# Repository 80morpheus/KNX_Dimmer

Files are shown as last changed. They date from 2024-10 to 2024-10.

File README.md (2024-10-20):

# KNX Dimmer
up to 16 channels possible
depends on the configuration

W = Single
CW = Cold/Warm White
RGB = RGB
RGBW = RGB+White
RGBCW = RGB+Cold/Warm White

Possible outputs:
3X  RGBCW
or
4x  RGBW
or
5X  RGB
or
8X  CW
or
16X W

CH1  S CW RGB RGBW RGBCW 
CH2  S CW RGB RGBW RGBCW 
CH3  S CW RGB RGBW RGBCW 
CH4  S CW RGB RGBW  
CH5  S CW RGB  
CH6  S CW      
CH7  S CW      
CH8  S CW      
CH9  S        
CH10 S        
CH11 S        
CH12 S        
CH13 S        
CH14 S        
CH15 S        
CH16 S         

# dimm bedingung
wenn abs oder rel dimmen dann nur bis min wert
wenn ausschalten, dann aus und optional farbwerte auf standard zurück setzen

single ist easy -> zwischen min und max

cw -> ginge auch zwischen min und max
      cw werte ??? müßte zwei min um evtl aus zu vermeiden
      ets eingabe farbtemp für c + w
      ets regler für temperatur gibt prozentual an welche der beiden wo steht
      links = nur c wird gesteuert und w ist dann 0
      mitte = beide selber wert
      rechts = nur w wird gesteuert und c ist dann 0

rgb -> dimmt nur von 0 bis setpoint
      min wert macht keinen sinn da dann zu komplizierte berechnungen

rgbw -> siehe rgb
      wie wird w behandelt ??? einzelnes licht objekt

rgbcw -> wie wird c und w behandelt ??? einzelnes licht objekt
      ets eingabe farbtemp für c + w
      ets standard wert - wird nach aus wieder aktiv ja/nein
      rgb dimmt von 0 bis setpoint

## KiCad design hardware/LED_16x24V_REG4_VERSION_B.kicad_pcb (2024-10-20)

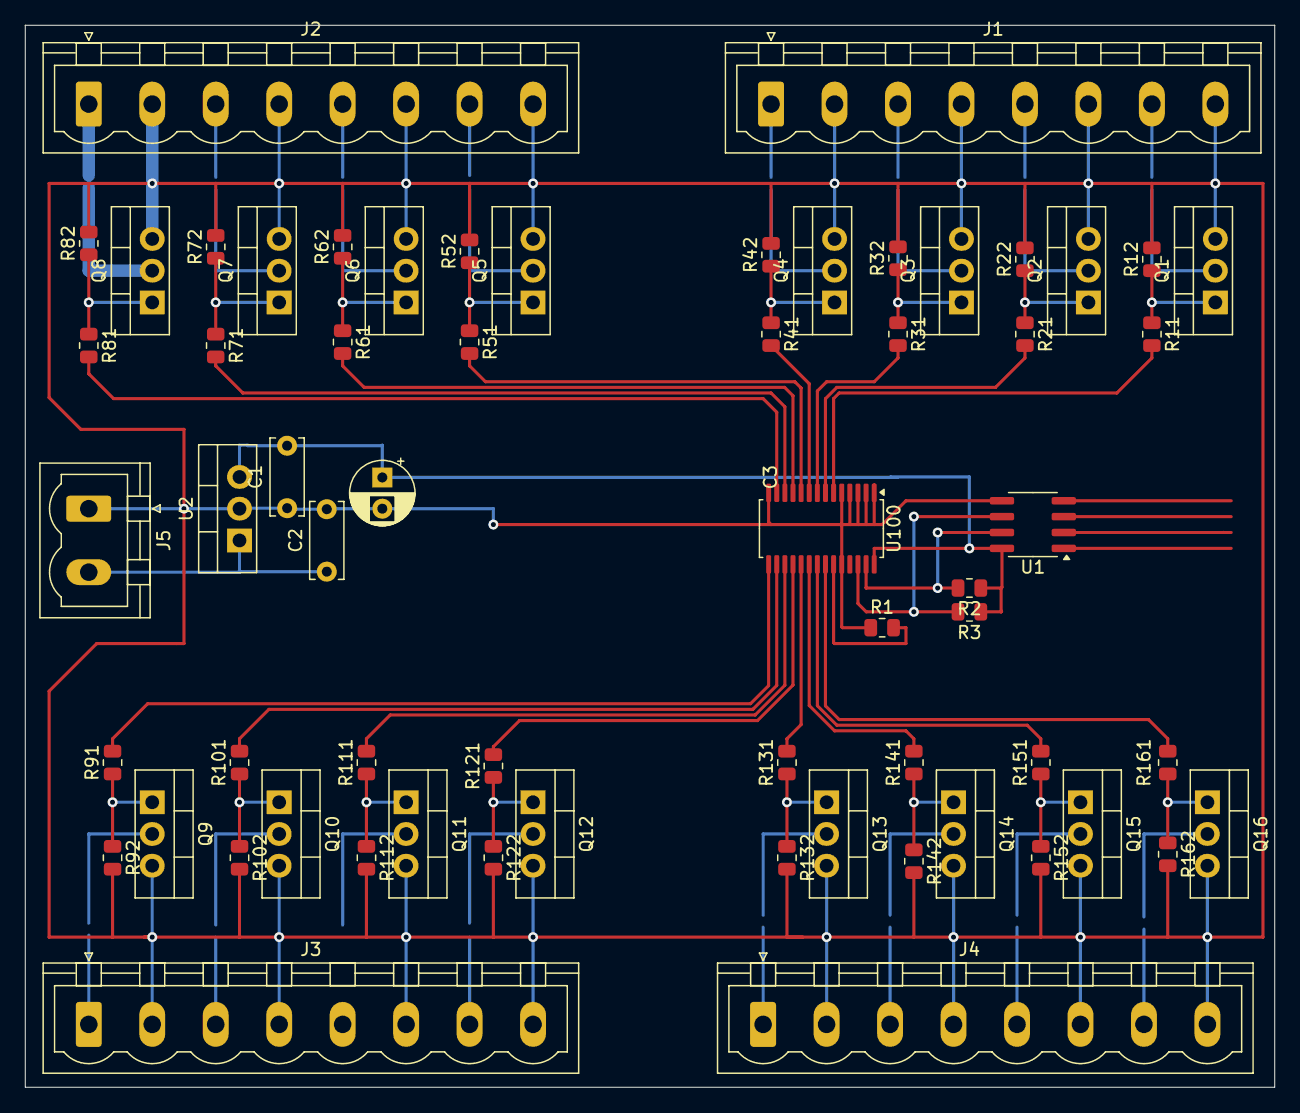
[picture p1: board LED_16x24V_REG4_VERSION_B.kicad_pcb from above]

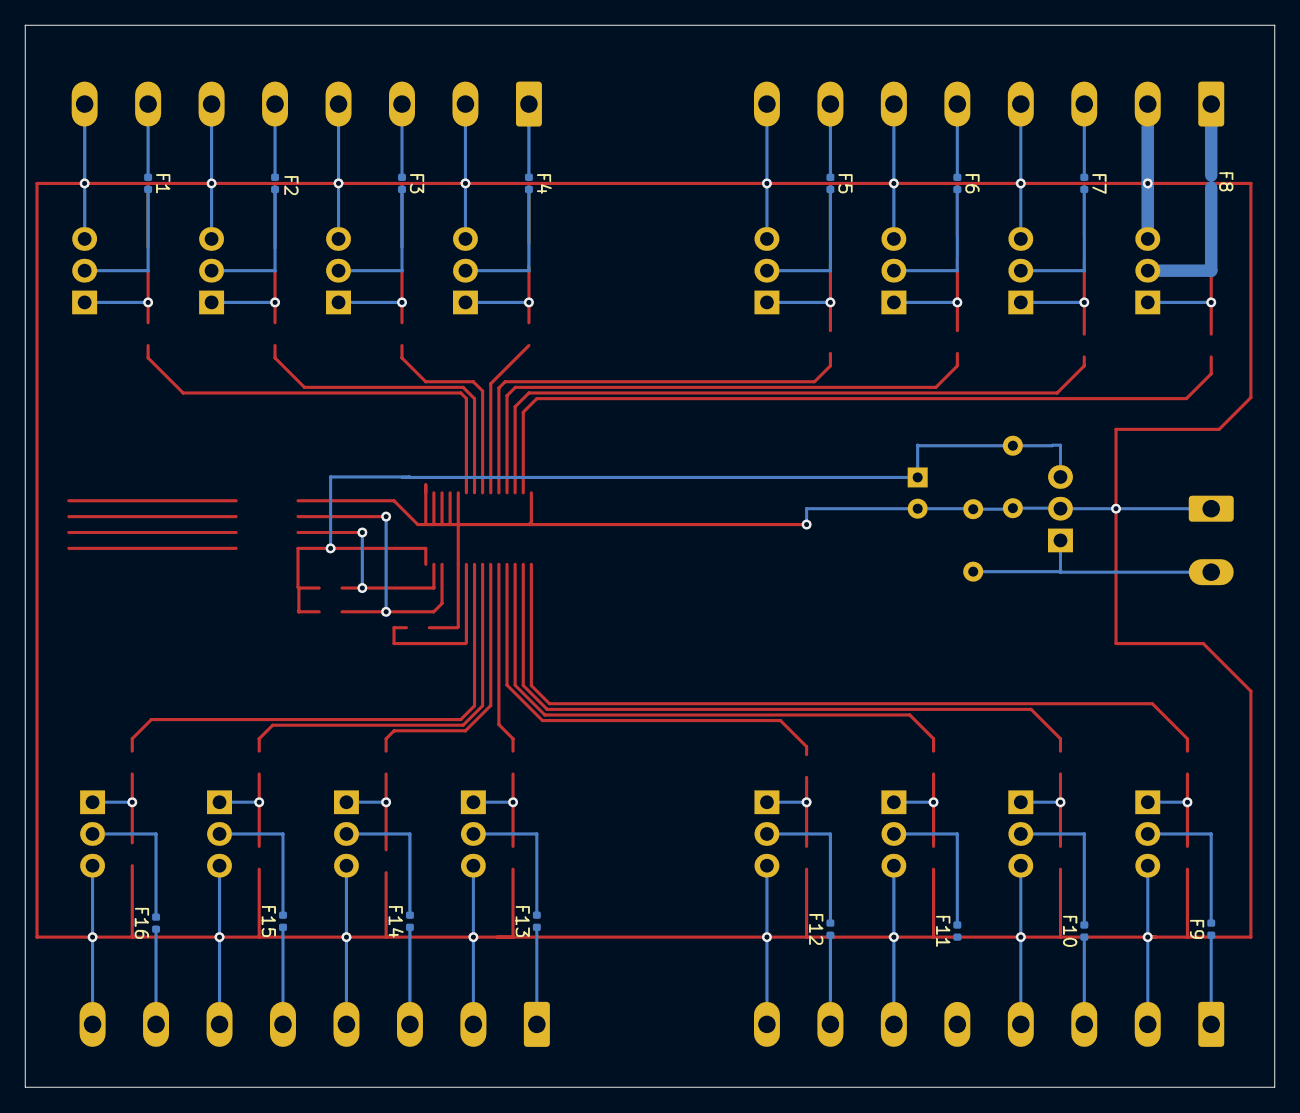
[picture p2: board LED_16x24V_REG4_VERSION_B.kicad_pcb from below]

Board: 2 copper layers, 100.0 x 85.0 mm, 78 parts (16 on the bottom side), 66 nets.

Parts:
C1: 0.1µF; C_Disc_D6.0mm_W2.5mm_P5.00mm
C2: 0.33µF; C_Disc_D6.0mm_W2.5mm_P5.00mm
C3: 100µF; CP_Radial_D5.0mm_P2.50mm
F1, F2, F3, F4, F5, F6, F7, F8, F9, F10, F11, F12, F13, F14, F15, F16: Fuse; Fuse_0402_1005Metric
J1, J2, J3, J4: Conn_01x08; PhoenixContact_MSTBVA_2,5_8-G-5,08_1x08_P5.08mm_Vertical
J5: Conn_01x02; PhoenixContact_MSTBVA_2,5_2-G-5,08_1x02_P5.08mm_Vertical
Q1, Q2, Q3, Q4, Q5, Q6, Q7, Q8, Q9, Q10, Q11, Q12, Q13, Q14, Q15, Q16: IRF3205; TO-220-3_Vertical
R1, R11, R12, R21, R22, R31, R32, R41, R42, R51, R52, R61, R62, R71, R72, R81, R82, R91, R92, R101, R102, R111, R112, R121, R122, R131, R132, R141, R142, R151, R152, R161, R162: R; R_0805_2012Metric
R2, R3: 10k; R_0805_2012Metric
U1: ADuM1250; SOIC-8_3.9x4.9mm_P1.27mm
U2: L7806; TO-220-3_Vertical
U100: PCA9685PW; TSSOP-28_4.4x9.7mm_P0.65mm

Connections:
GND_LED: C1.1, C2.2, C3.2, F7.1, F7.2, F8.1, F8.2, J1.2, J1.4, J1.6, J1.8, J2.1, J2.2, J2.3, J2.4, J2.6, J2.8, J3.2, J3.4, J3.6, J3.8, J4.2, J4.4, J4.6, J4.8, J5.1, Q1.3 (S), Q2.3 (S), Q3.3 (S), Q4.3 (S), Q5.3 (S), Q6.3 (S), Q7.2 (D), Q7.3 (S), Q8.2 (D), Q8.3 (S), Q9.3 (S), Q10.3 (S), Q11.3 (S), Q12.3 (S), Q13.3 (S), Q14.3 (S), Q15.3 (S), Q16.3 (S), R1.1, R12.2, R22.2, R32.2, R42.2, R52.2, R62.2, R72.2, R82.2, R92.2, R102.2, R112.2, R122.2, R132.2, R142.2, R152.2, R162.2, U1.5 (GND2), U2.2 (GND), U100.1 (A0), U100.2 (A1), U100.3 (A2), U100.4 (A3), U100.5 (A4), U100.14 (VSS), U100.24 (A5)
unnamed: F4.1, J1.1
unnamed: F3.1, J1.3
unnamed: F2.1, J1.5
unnamed: F1.1, J1.7
unnamed: F6.1, J2.5
unnamed: F5.1, J2.7
unnamed: F9.1, J3.1
unnamed: F10.1, J3.3
unnamed: F11.1, J3.5
unnamed: F12.1, J3.7
unnamed: F13.1, J4.1
unnamed: F14.1, J4.3
unnamed: F15.1, J4.5
unnamed: F16.1, J4.7
unnamed: C2.1, J5.2, U2.1 (IN)
unnamed: F1.2, Q1.2 (D)
unnamed: Q1.1 (G), R11.1, R12.1
unnamed: F2.2, Q2.2 (D)
unnamed: Q2.1 (G), R21.1, R22.1
unnamed: F3.2, Q3.2 (D)
unnamed: Q3.1 (G), R31.1, R32.1
unnamed: F4.2, Q4.2 (D)
unnamed: Q4.1 (G), R41.1, R42.1
unnamed: F5.2, Q5.2 (D)
unnamed: Q5.1 (G), R51.1, R52.1
unnamed: F6.2, Q6.2 (D)
unnamed: Q6.1 (G), R61.1, R62.1
unnamed: Q7.1 (G), R71.1, R72.1
unnamed: Q8.1 (G), R81.1, R82.1
unnamed: F9.2, Q9.2 (D)
unnamed: Q9.1 (G), R91.1, R92.1
unnamed: F10.2, Q10.2 (D)
unnamed: Q10.1 (G), R101.1, R102.1
unnamed: F11.2, Q11.2 (D)
unnamed: Q11.1 (G), R111.1, R112.1
unnamed: F12.2, Q12.2 (D)
unnamed: Q12.1 (G), R121.1, R122.1
unnamed: F13.2, Q13.2 (D)
unnamed: Q13.1 (G), R131.1, R132.1
unnamed: F14.2, Q14.2 (D)
unnamed: Q14.1 (G), R141.1, R142.1
unnamed: F15.2, Q15.2 (D)
unnamed: Q15.1 (G), R151.1, R152.1
unnamed: F16.2, Q16.2 (D)
unnamed: Q16.1 (G), R161.1, R162.1
unnamed: R3.2, U1.6 (SCL2), U100.26 (SCL)
unnamed: R2.2, U1.7 (SDA2), U100.27 (SDA)
unnamed: C1.2, C3.1, R2.1, R3.1, U1.8 (VDD2), U2.3 (OUT), U100.28 (VDD)
unnamed: R11.2, U100.6 (LED0)
unnamed: R21.2, U100.7 (LED1)
unnamed: R31.2, U100.8 (LED2)
unnamed: R41.2, U100.9 (LED3)
unnamed: R51.2, U100.10 (LED4)
unnamed: R61.2, U100.11 (LED5)
unnamed: R71.2, U100.12 (LED6)
unnamed: R81.2, U100.13 (LED7)
unnamed: R91.2, U100.15 (LED8)
unnamed: R101.2, U100.16 (LED9)
unnamed: R111.2, U100.17 (LED10)
unnamed: R121.2, U100.18 (LED11)
unnamed: R131.2, U100.19 (LED12)
unnamed: R141.2, U100.20 (LED13)
unnamed: R151.2, U100.21 (LED14)
unnamed: R161.2, U100.22 (LED15)
unnamed: R1.2, U100.23 (~OE)

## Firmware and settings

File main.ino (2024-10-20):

#include <Arduino.h>
#define MASK_VERSION 0x07B0
#define USE_RP2040_EEPROM_EMULATION
#include <knx.h>
//#include <Wire.h>
#include "dimmer.h"
int ch_num = 0;
Dimmer dimmer(2);







void setup() 
{
    knx.readMemory();
    if ( knx.configured() )
    {
      //Wire.begin();
      dimmer.init();
      for ( int i=1; i<17; i++)
      {
              if ( knx.paramInt(i*10) > 0 )   {ch_num++ ;  }
      }
      dimmer.knxParam(ch_num);

      dimmer.setGroupObject();
      dimmer.setupCallback();
    }
    else
    {
          knx.progMode(true);
    }
  dimmer.setStart();
}



void loop()
{
    knx.loop();
    if ( knx.configured() )
    {
          dimmer.loop();
    }

}

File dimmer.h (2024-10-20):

#include <Arduino.h>
#include <knx.h>

#ifndef Dimmer_h
#define Dimmer_h

#define go_ch01_switch knx.getGroupObject(10)
#define go_ch01_reldim knx.getGroupObject(11)
#define go_ch01_absdim knx.getGroupObject(12)
#define go_ch01_color  knx.getGroupObject(13)
#define go_ch01_temp   knx.getGroupObject(14)
#define go_ch01_state  knx.getGroupObject(15)
#define go_ch01_dimmer knx.getGroupObject(16)

#define go_ch02_switch knx.getGroupObject(20)
#define go_ch02_reldim knx.getGroupObject(21)
#define go_ch02_absdim knx.getGroupObject(23)
#define go_ch02_color  knx.getGroupObject(24)
#define go_ch02_temp   knx.getGroupObject(25)
#define go_ch02_state  knx.getGroupObject(26)
#define go_ch02_dimmer knx.getGroupObject(27)

#define go_ch03_switch knx.getGroupObject(30)
#define go_ch03_reldim knx.getGroupObject(31)
#define go_ch03_absdim knx.getGroupObject(32)
#define go_ch03_color  knx.getGroupObject(33)
#define go_ch03_temp   knx.getGroupObject(34)
#define go_ch03_state  knx.getGroupObject(35)
#define go_ch03_dimmer knx.getGroupObject(36)

#define go_ch04_switch knx.getGroupObject(40)
#define go_ch04_reldim knx.getGroupObject(41)
#define go_ch04_absdim knx.getGroupObject(42)
#define go_ch04_color  knx.getGroupObject(43)
#define go_ch04_temp   knx.getGroupObject(44)
#define go_ch04_state  knx.getGroupObject(45)
#define go_ch04_dimmer knx.getGroupObject(46)

#define go_ch05_switch knx.getGroupObject(50)
#define go_ch05_reldim knx.getGroupObject(51)
#define go_ch05_absdim knx.getGroupObject(52)
#define go_ch05_color  knx.getGroupObject(53)
#define go_ch05_temp   knx.getGroupObject(54)
#define go_ch05_state  knx.getGroupObject(55)
#define go_ch05_dimmer knx.getGroupObject(56)

#define go_ch06_switch knx.getGroupObject(60)
#define go_ch06_reldim knx.getGroupObject(61)
#define go_ch06_absdim knx.getGroupObject(62)
#define go_ch06_color  knx.getGroupObject(63)
#define go_ch06_temp   knx.getGroupObject(64)
#define go_ch06_state  knx.getGroupObject(65)
#define go_ch06_dimmer knx.getGroupObject(66)

#define go_ch07_switch knx.getGroupObject(70)
#define go_ch07_reldim knx.getGroupObject(71)
#define go_ch07_absdim knx.getGroupObject(72)
#define go_ch07_color  knx.getGroupObject(73)
#define go_ch07_temp   knx.getGroupObject(74)
#define go_ch07_state  knx.getGroupObject(75)
#define go_ch07_dimmer knx.getGroupObject(76)

#define go_ch08_switch knx.getGroupObject(80)
#define go_ch08_reldim knx.getGroupObject(81)
#define go_ch08_absdim knx.getGroupObject(82)
#define go_ch08_color  knx.getGroupObject(83)
#define go_ch08_temp   knx.getGroupObject(84)
#define go_ch08_state  knx.getGroupObject(85)
#define go_ch08_dimmer knx.getGroupObject(86)

#define go_ch09_switch knx.getGroupObject(90)
#define go_ch09_reldim knx.getGroupObject(91)
#define go_ch09_absdim knx.getGroupObject(92)
#define go_ch09_color  knx.getGroupObject(93)
#define go_ch09_temp   knx.getGroupObject(94)
#define go_ch09_state  knx.getGroupObject(95)
#define go_ch09_dimmer knx.getGroupObject(96)

#define go_ch10_switch knx.getGroupObject(100)
#define go_ch10_reldim knx.getGroupObject(101)
#define go_ch10_absdim knx.getGroupObject(102)
#define go_ch10_color  knx.getGroupObject(103) 
#define go_ch10_temp   knx.getGroupObject(104)
#define go_ch10_state  knx.getGroupObject(105)
#define go_ch10_dimmer knx.getGroupObject(106)

#define go_ch11_switch knx.getGroupObject(110)
#define go_ch11_reldim knx.getGroupObject(111)
#define go_ch11_absdim knx.getGroupObject(112)
#define go_ch11_color  knx.getGroupObject(113)
#define go_ch11_temp   knx.getGroupObject(114)
#define go_ch11_state  knx.getGroupObject(115)
#define go_ch11_dimmer knx.getGroupObject(116)

#define go_ch12_switch knx.getGroupObject(120)
#define go_ch12_reldim knx.getGroupObject(121)
#define go_ch12_absdim knx.getGroupObject(122)
#define go_ch12_color  knx.getGroupObject(123)
#define go_ch12_temp   knx.getGroupObject(124)
#define go_ch12_state  knx.getGroupObject(125)
#define go_ch12_dimmer knx.getGroupObject(126)

#define go_ch13_switch knx.getGroupObject(130)
#define go_ch13_reldim knx.getGroupObject(131)
#define go_ch13_absdim knx.getGroupObject(132)
#define go_ch13_color  knx.getGroupObject(133)
#define go_ch13_temp   knx.getGroupObject(134)
#define go_ch13_state  knx.getGroupObject(135)
#define go_ch13_dimmer knx.getGroupObject(136)

#define go_ch14_switch knx.getGroupObject(140)
#define go_ch14_reldim knx.getGroupObject(141)
#define go_ch14_absdim knx.getGroupObject(142)
#define go_ch14_color  knx.getGroupObject(143) 
#define go_ch14_temp   knx.getGroupObject(144)
#define go_ch14_state  knx.getGroupObject(145)
#define go_ch14_dimmer knx.getGroupObject(146)

#define go_ch15_switch knx.getGroupObject(150)
#define go_ch15_reldim knx.getGroupObject(151)
#define go_ch15_absdim knx.getGroupObject(152)
#define go_ch15_color  knx.getGroupObject(153)
#define go_ch15_temp   knx.getGroupObject(154)
#define go_ch15_state  knx.getGroupObject(155)
#define go_ch15_dimmer knx.getGroupObject(156)

#define go_ch16_switch knx.getGroupObject(160)
#define go_ch16_reldim knx.getGroupObject(161)
#define go_ch16_absdim knx.getGroupObject(162)
#define go_ch16_color  knx.getGroupObject(163)
#define go_ch16_temp   knx.getGroupObject(164)
#define go_ch16_state  knx.getGroupObject(165)
#define go_ch16_dimmer knx.getGroupObject(166)
//....
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
